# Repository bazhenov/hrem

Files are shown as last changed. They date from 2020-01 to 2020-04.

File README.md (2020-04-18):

# HREM



This project contains firware code and KiCad schematics/PCB files for simple door latch reminder.

## The problem

Me and my wife forget to close our flat entrance door from time to time. What will you do about that? :)

This project is simple hardware solution to remind us about open door. It's not the simplest nor most elegant solution, but more like excuse for practicing skills in embedded software development and electrical engineering.

## The solution

Solution is quite simple:

1. door latch has magnet on it's end;
1. hall effect sensor integrated into door frame right near latch with magnet;
1. μC powering up hall sensor once in a while and check magnet presense (hence door is closed);
1. buzzer goes on if latch is open.

## Part list

Complete BOM is in project files, but here are key parts used in a project:

1. [ATTiny85] as a μC
1. [Honeywell SS49][SS19] hall effect sensor;
1. [HT7733] as a voltage boost up controller. Single AAA battery is required.

## Building firmware

You need to have standart AVR toolchain is installed (e.g. `avr-gcc`, `avr-objcopy`...). Beyond that building firmware is as simple as:

```
$ make
```

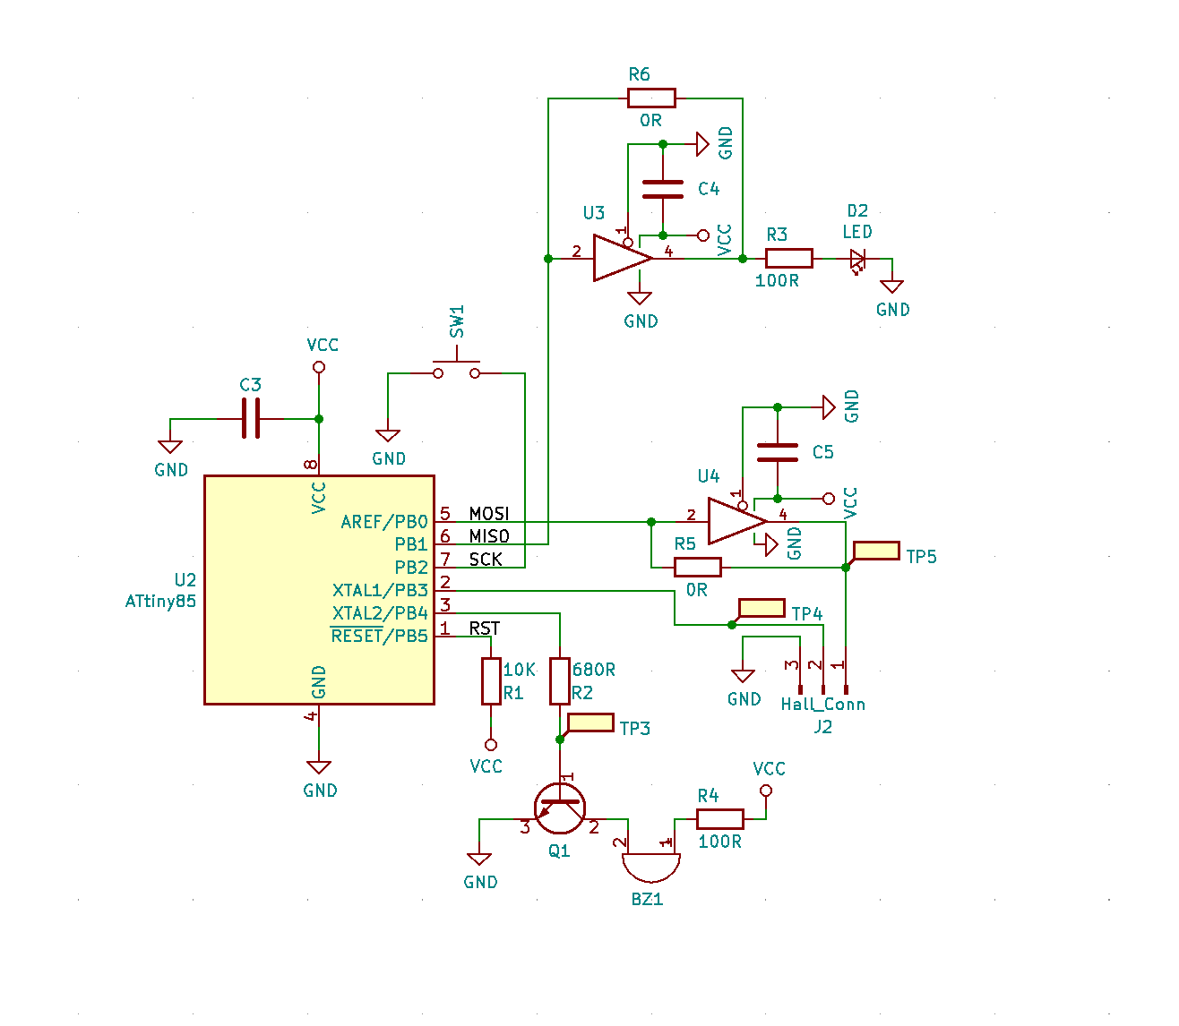
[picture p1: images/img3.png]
schematics

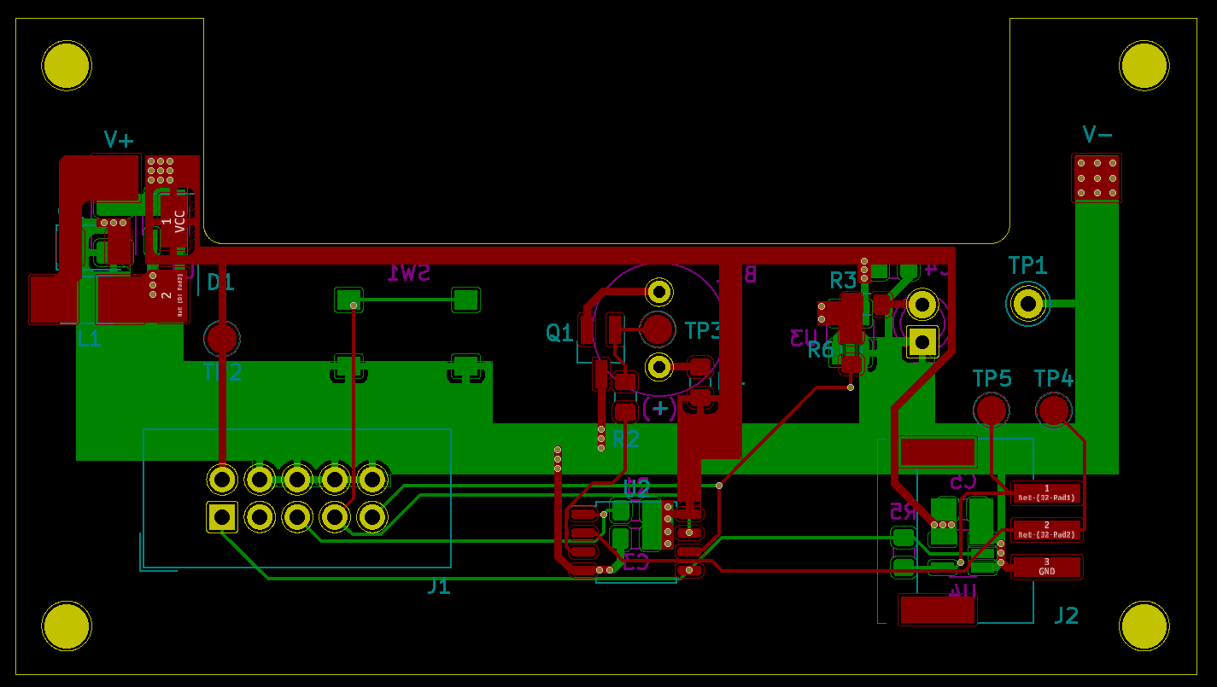
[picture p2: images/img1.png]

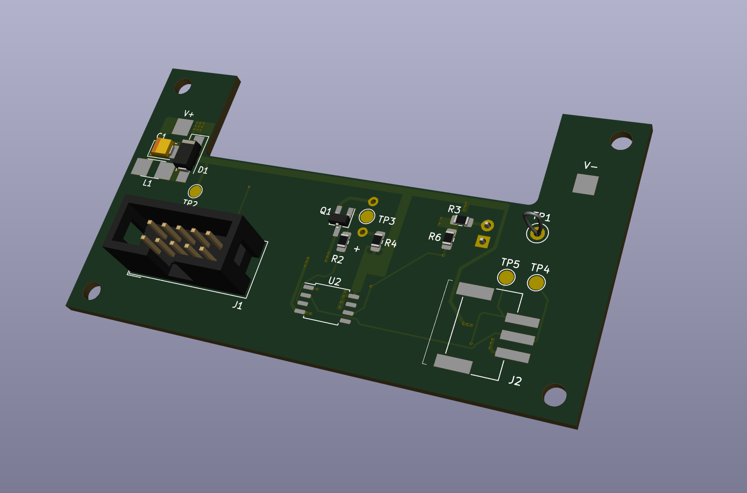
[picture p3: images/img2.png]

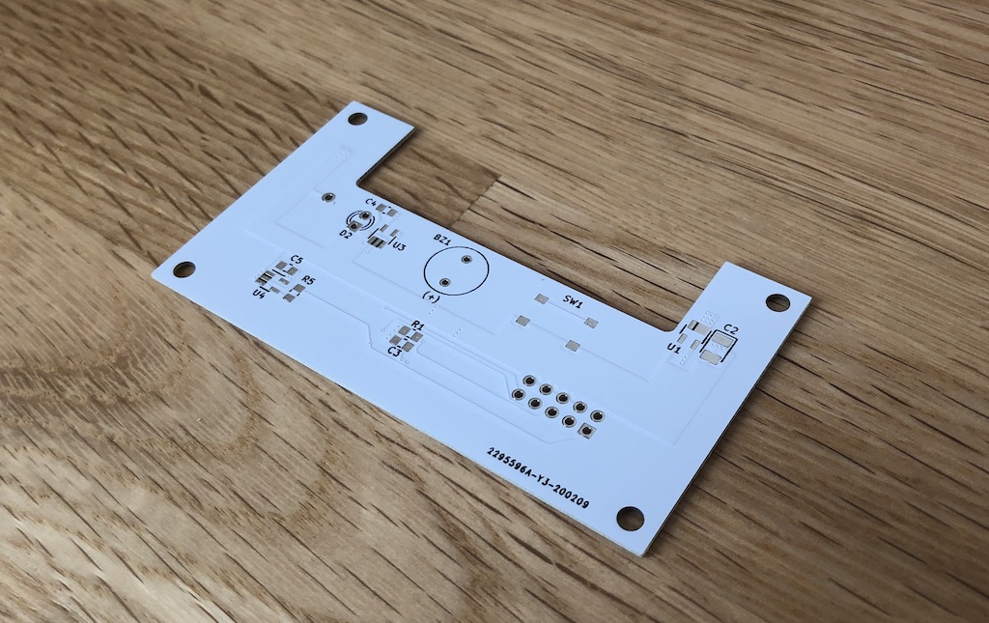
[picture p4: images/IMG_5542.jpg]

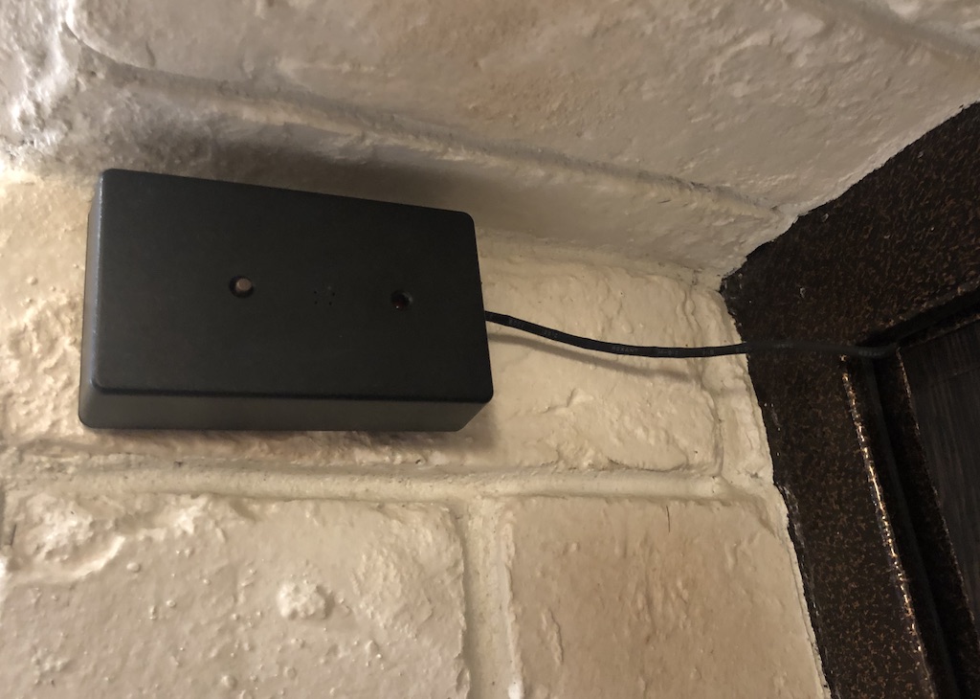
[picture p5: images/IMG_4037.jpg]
Assembled


[SS19]: https://eu.mouser.com/datasheet/2/187/SS49-1168552.pdf
[HT7733]: https://img.ozdisan.com/ETicaret_Dosya/349361_8060324.pdf
[attiny85]: https://ww1.microchip.com/downloads/en/DeviceDoc/Atmel-2586-AVR-8-bit-Microcontroller-ATtiny25-ATtiny45-ATtiny85_Datasheet.pdf

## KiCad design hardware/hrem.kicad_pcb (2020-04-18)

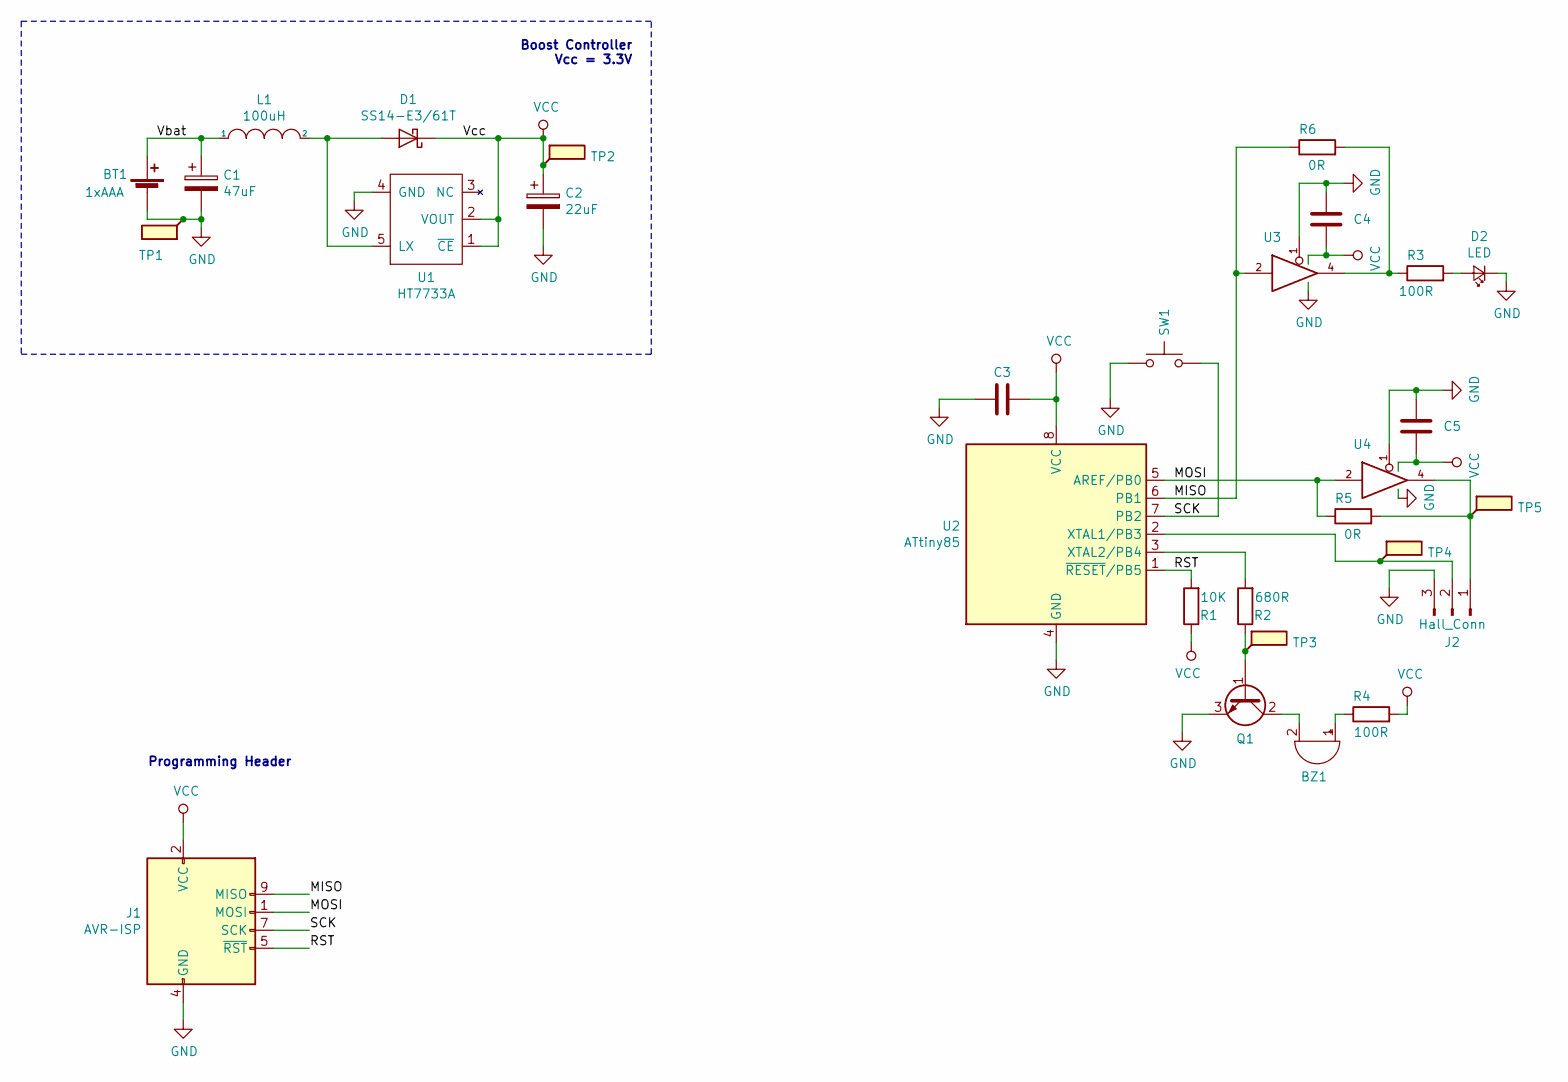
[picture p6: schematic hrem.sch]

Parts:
BT1: 1xAAA; AAA battery
BZ1: Buzzer; buzzer
C1: 47uF; CP_EIA-3528-15_AVX-H_Pad1.50x2.35mm_HandSolder; Part C22036
C2: 22uF; CP_EIA-3528-15_AVX-H_Pad1.50x2.35mm_HandSolder; Part C7198
C3, C4, C5: 100nF; C_0805_2012Metric_Pad1.15x1.40mm_HandSolder; Part C354369
D1: SS14-E3/61T; D_SMA_Handsoldering; Part C47460
D2: LED; LED_D3.0mm
J1: AVR-ISP; IDC-Header_2x05_P2.54mm_Vertical
J2: Hall_Conn; X8821WRS-03-9TSN; Part C397433
L1: 100uH; Murata LQH43; Part C113087
Q1: MMBT4401-7-F; SOT-23_Handsoldering; Part C151826
R1: 10K; R_0805_2012Metric_Pad1.15x1.40mm_HandSolder; Part C103904
R2: 680R; R_0805_2012Metric_Pad1.15x1.40mm_HandSolder; Part C410034
R3, R4: 100R; R_0805_2012Metric_Pad1.15x1.40mm_HandSolder; Part C193990
R5, R6: 0R; R_0805_2012Metric_Pad1.15x1.40mm_HandSolder; Part C465486
SW1: SW_Push_Dual; Diptronics DTSM-65N; Part C224982
TP1: TestPoint_Flag; TestPoint_Loop_D2.50mm_Drill1.0mm
TP2, TP3, TP4, TP5: TestPoint_Flag; TestPoint_Pad_D2.0mm
U1: HT7733A; SOT-23-5_HandSoldering
U2: ATtiny85; SOIC-8_5.23x5.23mm_P1.27mm
U3, U4: 74LVC1G125; SOT-23-5_HandSoldering; Part C23654

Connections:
/MISO: J1.9 (MISO), R6.1, U2.6 (PB1), U3.2
/MOSI: J1.1 (MOSI), R5.1, U2.5 (AREF/PB0), U4.2
/RST: J1.5 (~RST), R1.2, U2.1 (~RESET~/PB5)
/SCK: J1.7 (SCK), SW1.2, U2.7 (PB2)
/Vbat: BT1.1 (+), C1.1, L1.1
GND: BT1.2 (-), C1.2, C2.2, C3.2, C4.2, C5.2, D2.1 (K), J1.4 (GND), J1.6 (GND), J1.8 (GND), J1.10 (GND), J2.3, Q1.3 (E), SW1.1, TP1.1, U1.4 (GND), U2.4 (GND), U3.1, U3.3 (GND), U4.1, U4.3 (GND)
unnamed: BZ1.1 (-), R4.1
unnamed: BZ1.2 (+), Q1.2 (C)
unnamed: D1.2 (A), L1.2, U1.5 (LX)
unnamed: D2.2 (A), R3.2
unnamed: J2.1, R5.2, TP5.1, U4.4
unnamed: J2.2, TP4.1, U2.2 (XTAL1/PB3)
unnamed: Q1.1 (B), R2.1, TP3.1
unnamed: R2.2, U2.3 (XTAL2/PB4)
unnamed: R3.1, R6.2, U3.4
VCC: C2.1, C3.1, C4.1, C5.1, D1.1 (K), J1.2 (VCC), R1.1, R4.2, TP2.1, U1.1 (~CE), U1.2 (VOUT), U2.8 (VCC), U3.5 (VCC), U4.5 (VCC)

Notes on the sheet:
Boost Controller Vcc = 3.3V
Programming Header

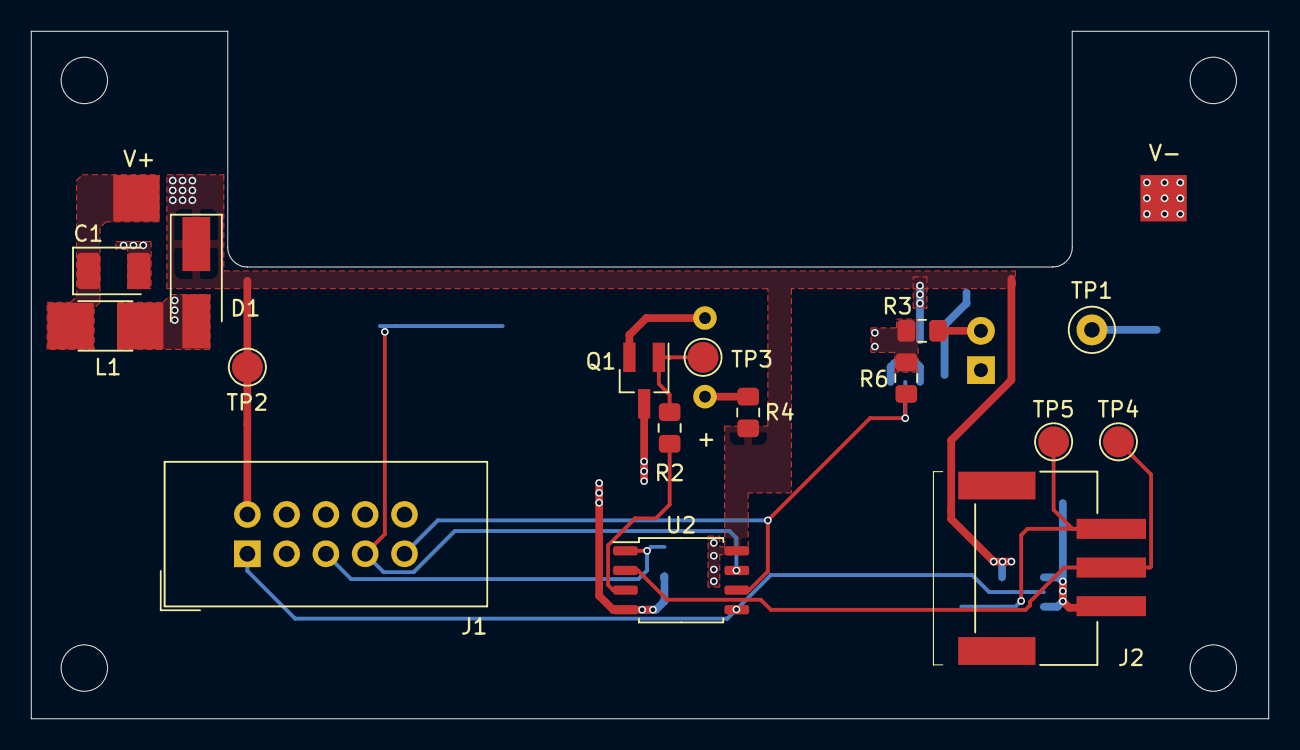
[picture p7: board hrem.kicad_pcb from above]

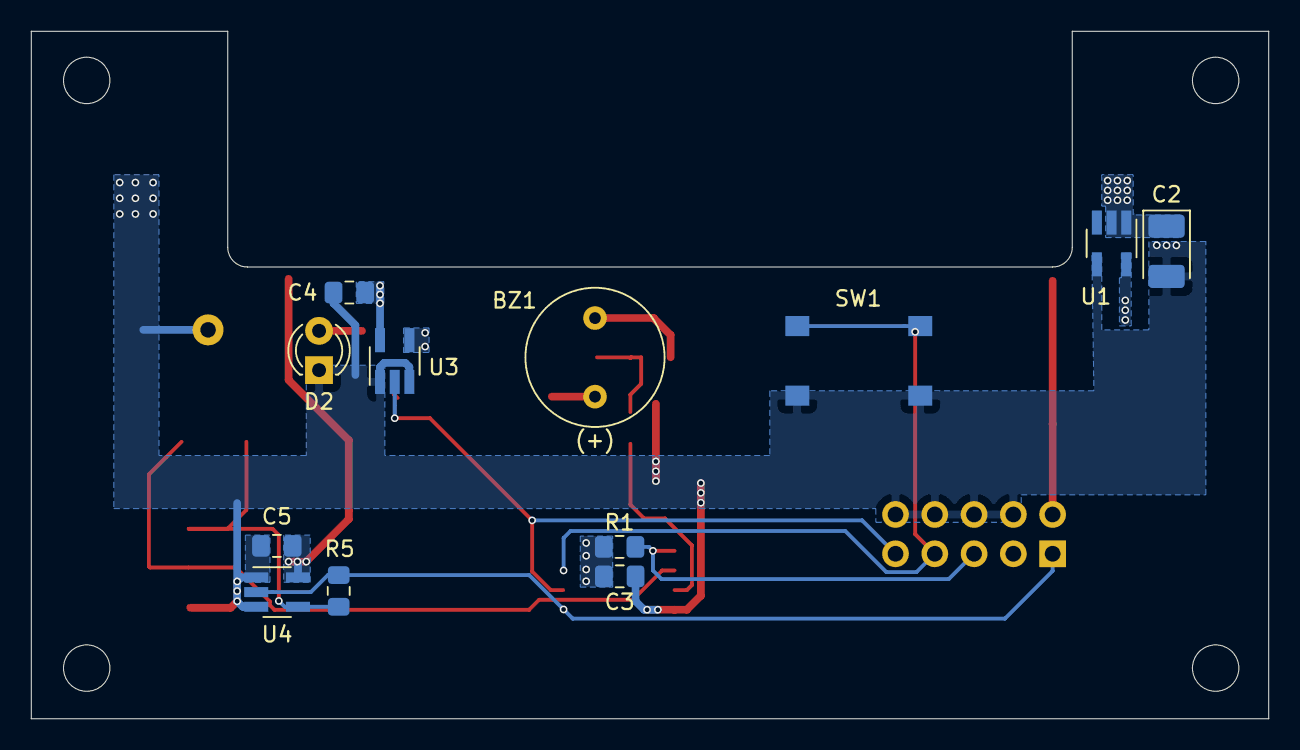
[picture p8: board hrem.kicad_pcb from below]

Board: 2 copper layers, 80.0 x 44.4 mm, 29 parts (12 on the bottom side), 16 nets.

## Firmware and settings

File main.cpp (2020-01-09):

#include <avr/io.h>
#include <util/delay.h>
#include <stdlib.h>
#include <avr/power.h>
#include <avr/sleep.h>
#include <avr/wdt.h>
#include <avr/interrupt.h>

// User button
#define PIN_BUTTON PINB2
#define PIN_LED PINB1
#define PIN_HALL_POWER PINB0
#define PIN_BUZZER PINB4

void beep() {
  int i;
  for (i=0; i<3; i++) {
    PORTB |= _BV(PIN_BUZZER);
    _delay_ms(50);
    PORTB &= ~_BV(PIN_BUZZER);
    _delay_ms(50);
  }
}

void setup() {
  cli();

  MCUSR &= ~_BV(WDRF); // Clear the reset flag

  /* Enabling watchdog */ {
    WDTCR |= _BV(WDCE) | _BV(WDE);
    WDTCR = _BV(WDP3) | _BV(WDP0) | _BV(WDIE);

    set_sleep_mode(SLEEP_MODE_PWR_DOWN);
  }

  // Enable button interrupt
    
  // Triggering interrupt on low level
  MCUCR |= (0 << ISC01) | (0 << ISC00);
  // Enabling interrupt on INT0 channel  
  GIMSK = 1 << INT0;

  SREG |= (1 << 7);

  sei();
}

void ledIndicate() {
  PORTB |= _BV(PIN_LED);
  _delay_ms(50);
  PORTB &= ~_BV(PIN_LED);
  _delay_ms(50);
}

ISR(INT0_vect) {
  cli();
  //beep();
  sei();
}

int readAdc() {
  ADMUX =
    (1 << ADLAR) |     // left shift result
    (0 << REFS1) |     // Sets ref. voltage to VCC, bit 1
    (0 << REFS0) |     // Sets ref. voltage to VCC, bit 0
    (0 << MUX3)  |     // use ADC3 for input (PB3)
    (0 << MUX2)  |     // use ADC3 for input (PB3)
    (1 << MUX1)  |     // use ADC3 for input (PB3)
    (1 << MUX0);       // use ADC3 for input (PB3)

  ADCSRA =
    (1 << ADEN)  |     // Enable ADC
    (0 << ADPS2) |     // set prescaler
    (0 << ADPS1) |     // set prescaler
    (0 << ADPS0);      // set prescaler

  ADCSRA |= _BV(ADSC);           // start ADC measurement
	while (ADCSRA & _BV(ADSC));  // wait till conversion complete
	return ADCH;
}

char isLatchClosed() {
  PORTB |= _BV(PIN_HALL_POWER);
  //_delay_ms(2000);
  int value = abs(readAdc() - 128);
  PORTB &= ~_BV(PIN_HALL_POWER);
  return value > 5;
}

void enterSleep() {
  // Disabling ADC
  ADCSRA = 0;

  // Disabling Hall Effect Sensor
  PORTB &= ~_BV(PIN_HALL_POWER);

  // Disable Brown out Detection
  sleep_bod_disable();

  wdt_reset();
  /* Now enter sleep mode. */
  sleep_mode();

  /* Re-enable the peripherals. */
  power_all_enable();
}

int	main(void) {
	setup();
	DDRB = _BV(PIN_HALL_POWER) | _BV(PIN_BUZZER) | _BV(PIN_LED);
  PORTB = _BV(PIN_BUTTON);

  for (;;) {
    cli();
    ledIndicate();
		if (!isLatchClosed()) {
			beep();
		}
    sei();
    enterSleep();
	}
	return 0;
}

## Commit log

2016-03-14 Первая рабочая версия
2016-03-14 Добавил bin/hex файлы в gitignore
2016-03-14 Поддержка индикаторного светодиода
2016-03-31 Первый рабочий прототип
    [hrem.brd, hrem.sch]
2016-03-31 Удалил ненужные файлы
2016-05-02 PCB improvements
    [hrem.brd, hrem.sch]
2016-06-19 SMD version
    [hrem.brd, hrem.sch]
2019-10-12 prototype of new version is commited
    [hrem.kicad_pcb, hrem.sch]
2019-10-19 hardware changes
    [hrem.sch]
2019-10-26 Some changes to schematics
    [hrem.sch]
2019-11-24 New rev
    [hrem.sch]
2020-01-02 Migration to new KiCad version
    [hrem.kicad_pcb, hrem.sch]
2020-01-03 Update ICSP footprint information
    [hrem.kicad_pcb, hrem.sch]
2020-01-05 Various imrovements
    - C++ templates are used to isolate pin management
    - flash-* targets are renamed to *.flash to improve shell experience
2020-01-05 LongPress implemented for Button
2020-01-12 KiCad new footprints
    [hrem.kicad_pcb, hrem.sch]
2020-01-17 Footprint change
    [hrem.sch]
2020-01-19 Work over schematics
    [hrem.kicad_pcb, hrem.sch]
2020-01-19 Button footprint added
    [hrem.kicad_pcb, hrem.sch]
2020-01-19 Boosting voltage regulator pcb layout
    [hrem.kicad_pcb]
2020-01-20 Buzzer and LED PCB layout
    [hrem.kicad_pcb]
2020-02-01 Work on PCB layout
    [hrem.kicad_pcb, hrem.sch]
2020-02-01 PCB layout all set
    [hrem.kicad_pcb]
2020-02-02 Buzzer PCB layout dimensions fixed
    [hrem.kicad_pcb]
2020-02-02 PCB tracks cleanup
    [hrem.kicad_pcb]
2020-02-02 Replace 68R with 100R on LED for component unification purposes (15mA current)
    [hrem.sch]
2020-02-02 PCB POWER trace for BZ1 and D2
    [hrem.kicad_pcb]
2020-02-02 Decoupling caps added on U3 and U4
    [hrem.kicad_pcb, hrem.sch]
2020-02-02 Schematic cleanup
    [hrem.sch]
2020-02-02 Revision updated on shcematics
    [hrem.sch]
2020-02-02 PCB ref names positioning and vendor part names
    [hrem.kicad_pcb, hrem.sch]
2020-02-09 First fabrication version
    [hrem-B_Cu.gbr, hrem-B_Mask.gbr, hrem-B_SilkS.gbr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]
2020-04-17 Fixed layout issue
    Q1 has invalid schematics symbol. Base and collector was swaped.
    [hrem.kicad_pcb, hrem.sch]
2020-04-18 Remove old files
    [hrem.brd, hrem.sch]
2020-04-18 README added
    [hrem-B_Cu.gbr, hrem-B_Mask.gbr, hrem-B_SilkS.gbr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]
